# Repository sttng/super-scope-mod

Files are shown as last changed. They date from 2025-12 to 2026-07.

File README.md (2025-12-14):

# super-scope-mod
Tracking, BT communication code, and 3D printer files to make SNES Super Scope work on LCD TVs

## Description
This is the companion code for *element14 Presents* episode 469: "Nintendo Super Scope Mod For Modern Televisions".

Nintendo Super Scope Mod For Modern Televisions (https://www.youtube.com/watch?v=_CQ7ApMLAM0)
 
element14 Community page: https://www.element14.com/community/docs/DOC-95663

# Bill of Material

| Product Name | Manufacturer | Quantity |
| --- | --- | --- |
| RPI4-MODBP-2GB - Single Board Computer, Raspberry Pi 4 Model B, BCM2711 SoC, 2GB DDR4 RAM, USB 3.0, PoE Enabled | RASPBERRY-PI | 1 |
| Development Board, Arduino Uno, ATmega328P MCU, 14 3.3V I/O, 6 Analogue Inputs, 6 PWM Outputs | ARDUINO | 1 |
| RPI NOIR CAMERA BOARD - Daughter Board, Raspberry Pi NoIR Camera Board, Version 2, Sony IMX219 8-Megapixel Sensor | RASPBERRY-PI | 1 |
| MP001243 - AXIAL FAN, RASPBERRY PI 4 POWER HAT CASE | MULTICOMP PRO | 1 |
| Infrared Emitter, High Speed, 850 nm, 3 °, T-1 3/4 (5mm), 10 mW/Sr, 10 ns, 10 ns | VISHAY | 4 |
| LM1881N Video Sync Separator chip | TI | 1 |
| MC14021BCP 8Bit Shift Register chip | Motorola | 1 |
| 680k Ohm resistor | | 1 |
| 0.1 µF ceramic capacitors | | 2 |

# Additional Parts

| Product Name |
| ------------ |
| 3 x 3" Infrared (87C) Polyester Filter |
| Moldable glue, black color |
| HC-06 Bluetooth 2.0 Module |
| 30cm Micro HDMI Male to Micro HDMI Female Extension Cable |
| 30cm USB Type C Extension Cable Male to Female |
| 50cm flat ribbon camera cable for Raspberry Pi cameras |

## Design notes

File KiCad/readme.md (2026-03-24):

# Arduino Nano Shield KiCad 9 files

An Arduino Nano shield version of the Super Scope Mod. It is supposed to go below an Arduino Nano. 
The orientation is marked with the USB (top) marker. This is where the Arduino Nanos USB port is supposed to be (on top), with the shield below.

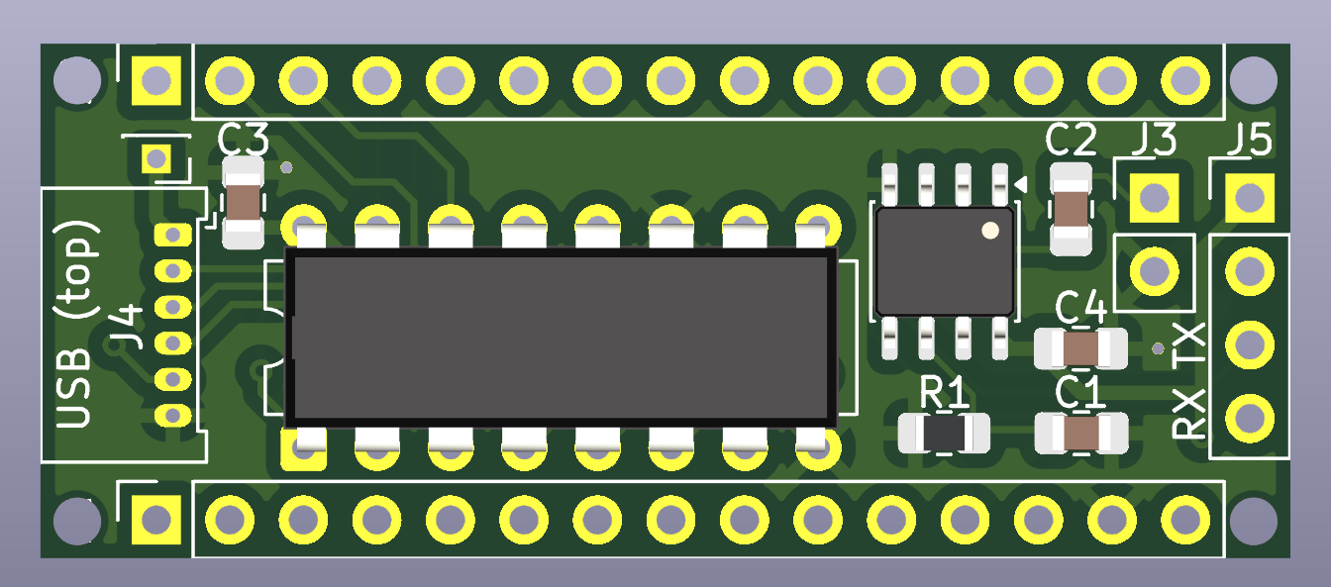
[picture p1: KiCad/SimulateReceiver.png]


## Device

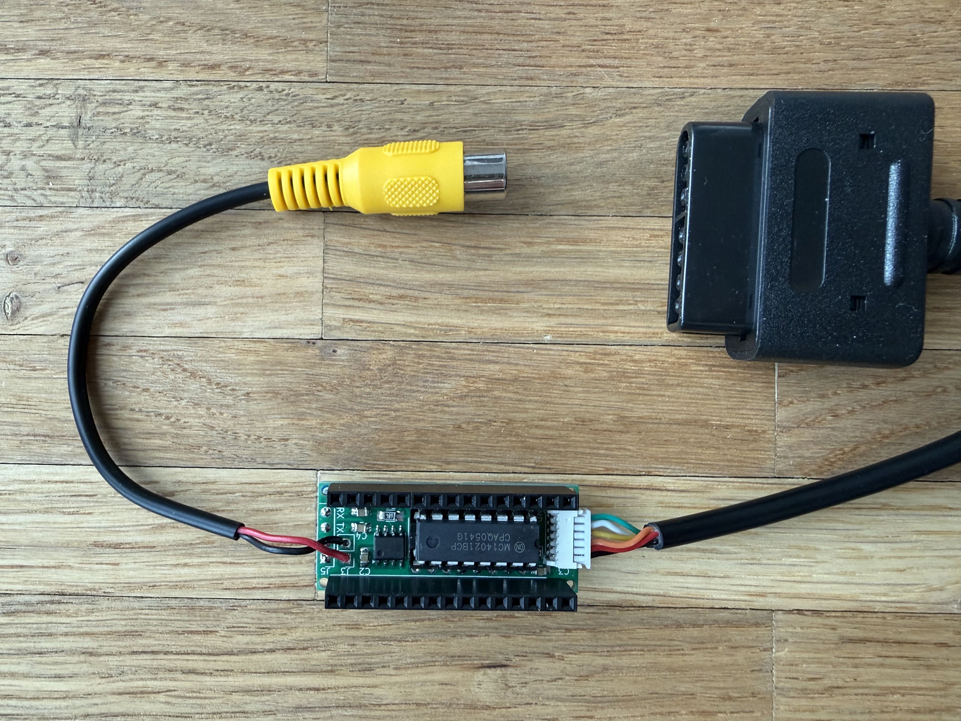
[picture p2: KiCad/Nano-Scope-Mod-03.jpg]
Prototype-1
 

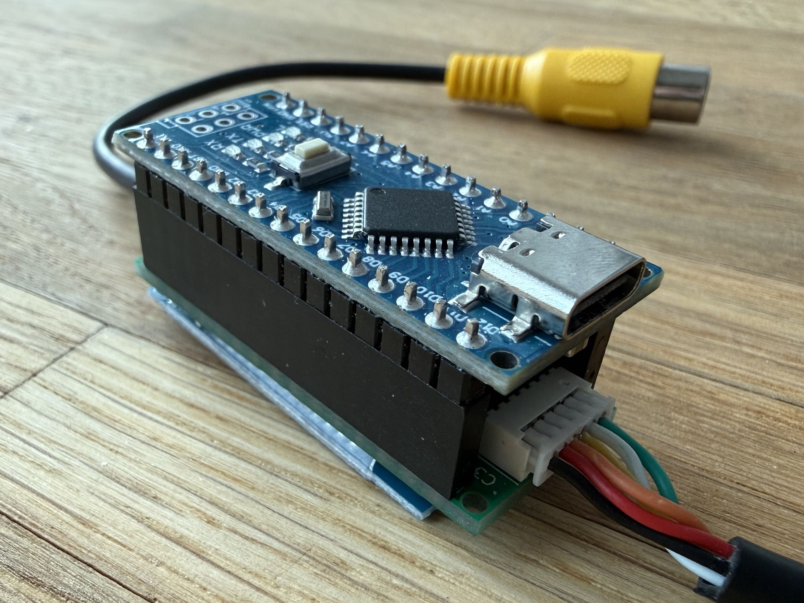
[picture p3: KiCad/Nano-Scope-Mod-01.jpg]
Prototype-3
 

## BoM

| Designator  | Footprint | Quantity | Description |
|---|---|---|---|
| J1, J2 | PinSocket_1x15_P2.54mm_Vertical | 2 | |
| J4 | Molex_PicoBlade_53048-0610_1x06_P1.25mm_Horizontal | 1 | |
| C1,C2,C3,C3 | C_0805_2012Metric_Pad1.18x1.45mm_HandSolder | 4 | 0.1µF |
| R1 | R_0805_2012Metric_Pad1.20x1.40mm_HandSolder | 1 | 680k |
| IC1 | DIP-16_W7.62mm | 1 | MC14021BCP |
| U1 | JEITA_SOIC-8_3.9x4.9mm_P1.27mm | 1 | LM1881M |

# ESP32-S3 Super Mini Shield KiCad 9 files

An ESP32-S3 Super Mini shield version of the Super Scope Mod. It is supposed to go below an ESP32-S3 Super Mini board. 
The orientation is marked with the USB (top) marker. This is where the ESP32-S3 Super Mini USB port is supposed to be (on top), with the shield below.

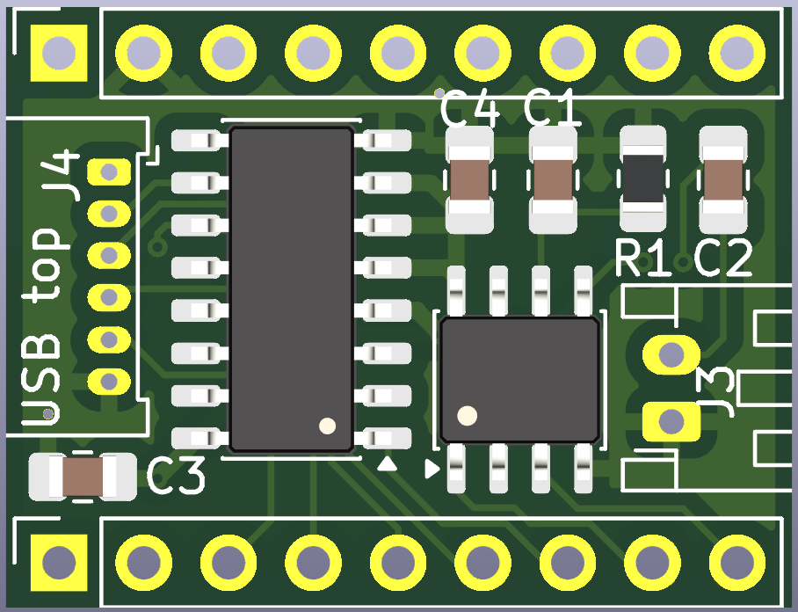
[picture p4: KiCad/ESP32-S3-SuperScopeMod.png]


## Device

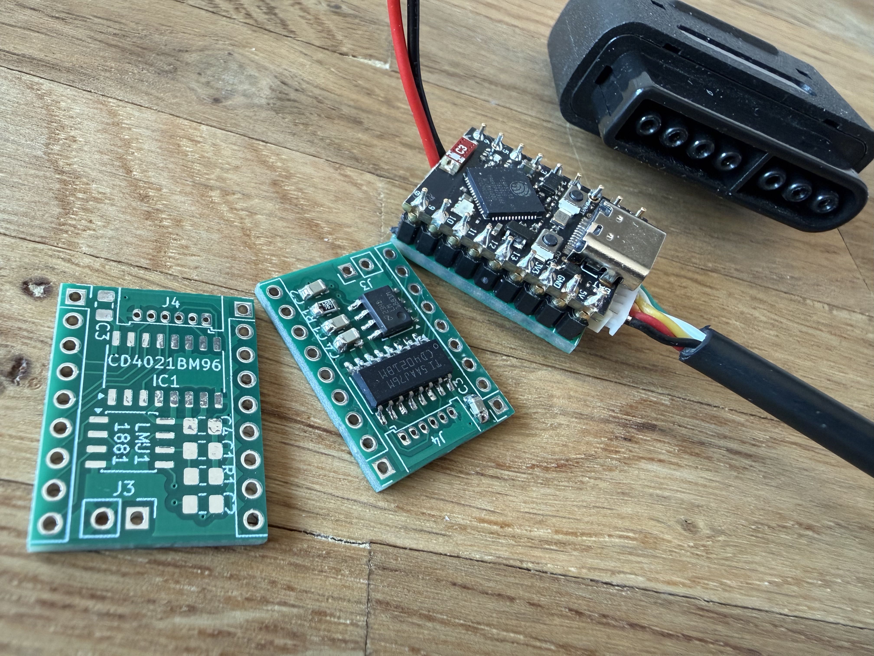
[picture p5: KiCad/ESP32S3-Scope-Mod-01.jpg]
Prototype-ESP32-1
 

## BoM

| Designator  | Footprint | Quantity | Description |
|---|---|---|---|
| J1, J2 | PinSocket_1x09_P2.54mm_Vertical | 2 | |
| J3 | JST PH 1x02 P2.00mm Horizontal | 1 | to Connect to Coax |
| J4 | Molex_PicoBlade_53048-0610_1x06_P1.25mm_Horizontal | 1 | |
| C1,C2,C3,C3 | C_0805_2012Metric_Pad1.18x1.45mm_HandSolder | 4 | 0.1µF |
| R1 | R_0805_2012Metric_Pad1.20x1.40mm_HandSolder | 1 | 680k |
| IC1 | JEITA_SOIC-16_3.9x9.9mm_P1.27mm | 1 | CD4021BM96 |
| U1 | JEITA_SOIC-8_3.9x4.9mm_P1.27mm | 1 | LM1881M |

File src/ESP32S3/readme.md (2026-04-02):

 For ESP32-S3 & ESP32-H2 Super Mini Dev Module

For serial output to work:
  Select Tools > USB CDC On Boot > Enabled from the Arduino IDE menus.

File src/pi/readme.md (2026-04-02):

1) Install OS and updates.
```
sudo apt update
sudo apt upgrade -y
```

2. Installing the LGPIO Library on the Raspberry Pi
https://pimylifeup.com/raspberry-pi-install-lgpio/

We must ensure that we have all the tools needed to compile the library.
```
sudo apt install unzip wget swig build-essential python3-dev python3-setuptools
```

Go to home dir

```
cd ~
```

Download the latest version of the LGPIO library code directly from GitHub

```
wget https://github.com/joan2937/lg/archive/master.zip
```

```
unzip master.zip
cd lg-master
```

```
make
```

```
sudo make install
```

Cleanup

```
cd
rm master.zip
rm -r -f ./lg-master
```

3 .Setup Python Env

```
sudo apt-get install python3-pip
```

```
python3 -m venv venv
source venv/bin/activate
```

```
pip3 install simplepyble
```

```
//pip3 install bleak
//pip3 install RPi.GPIO
pip3 install rpi-lgpio
pip3 install --upgrade imutils
pip3 install scipy
```

#Start Bluetooth Service:
```
sudo systemctl start bluetooth
```
#Unblock Bluetooth (if necessary):
```
sudo rfkill unblock bluetooth
```

Activate Power within bluetoothctl:
#bluetoothctl
Type power on
Type agent on
Type default-agent
Type exit

/usr/local/bin/bleak-lescan

# only Python
Option 1 - Main modules package: pip install opencv-python 

Option 2 - Full package (contains both main modules and contrib/extra modules): pip install opencv-contrib-python (check contrib/extra modules listing from OpenCV documentation)

Packages for server (headless) environments:

Option 3 - Headless main modules package: pip install opencv-python-headless

Option 4 - Headless full package (contains both main modules and contrib/extra modules): pip install opencv-contrib-python-headless

```
pip3 install opencv-contrib-python
```

# If building yourself

You need at least 2GB ZRAM. 

# Install zram tools

```
sudo apt install zram-tools
```

# Disable the current swap

```
sudo swapoff /dev/zram0
```

# Reset the device

```
sudo zramctl --reset /dev/zram0
```

# Set the new size and re-initialize as swap

```
sudo zramctl --find --size 2G --algorithm zstd
sudo mkswap /dev/zram0
sudo swapon /dev/zram0
```

https://qengineering.eu/install-opencv-lite-on-raspberry-pi.html

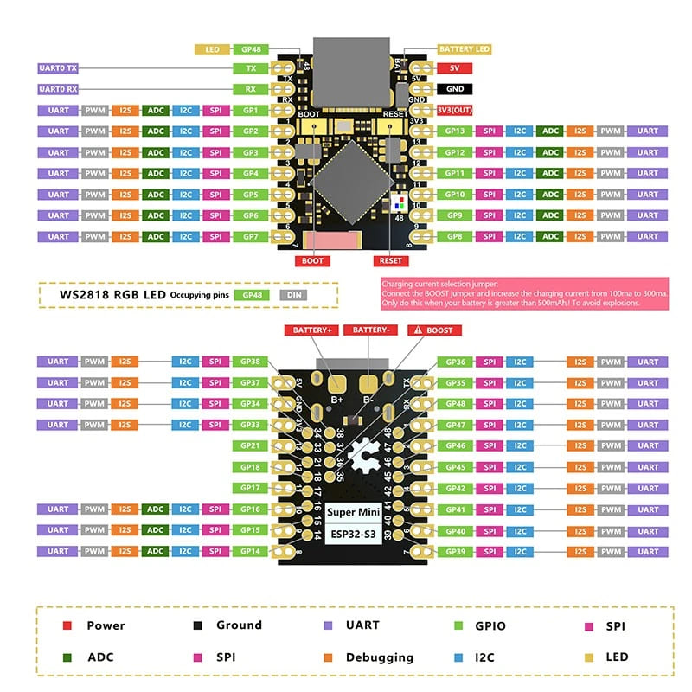
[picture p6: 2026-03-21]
KiCad/SimulateReceiver ESP32-S3-SuperMini/ESP32-S3-SuperMini-Pinout.jpg

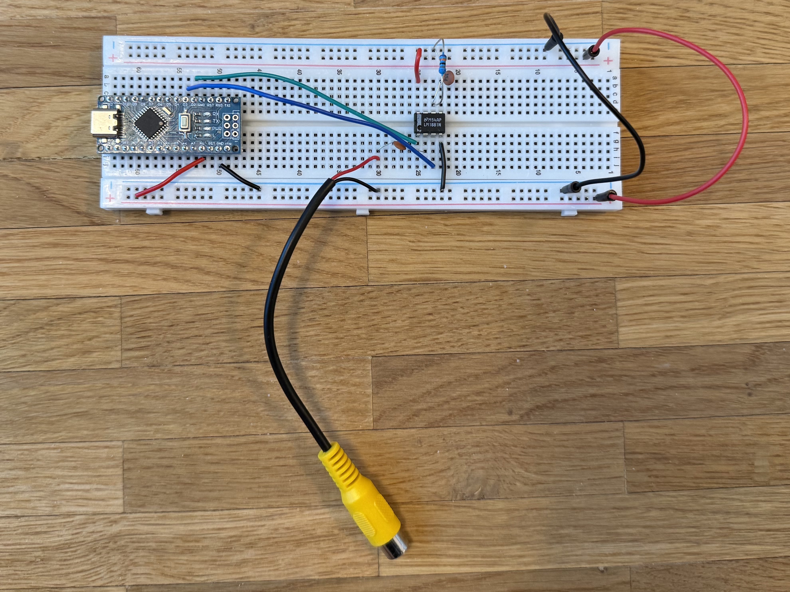
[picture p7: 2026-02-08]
src/arduino/count-screen-lines.jpg

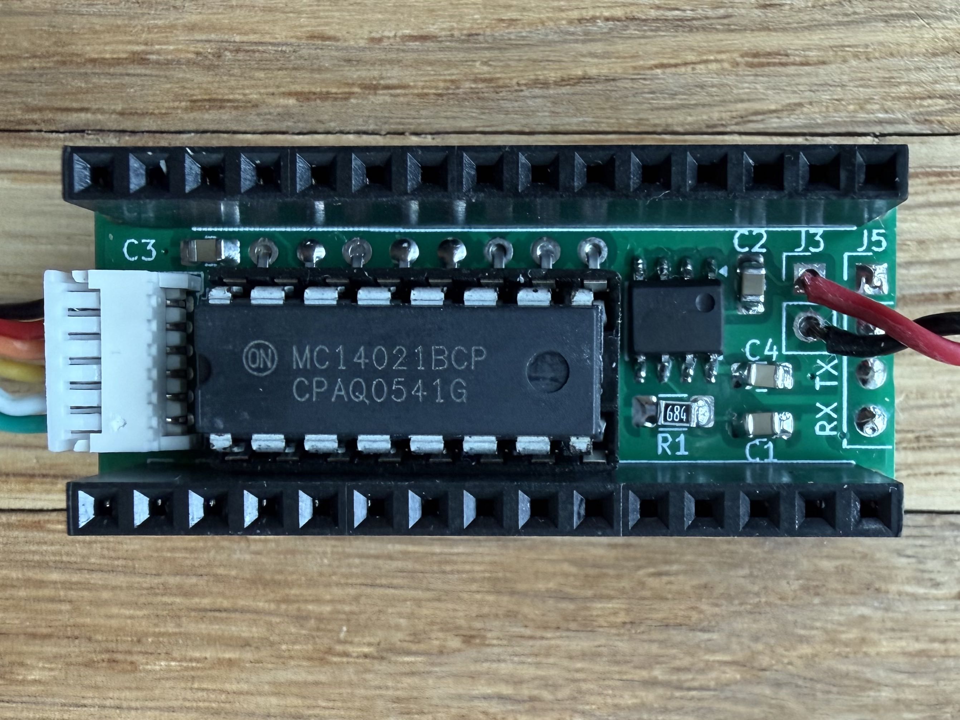
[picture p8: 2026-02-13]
KiCad/Nano-Scope-Mod-02.jpg

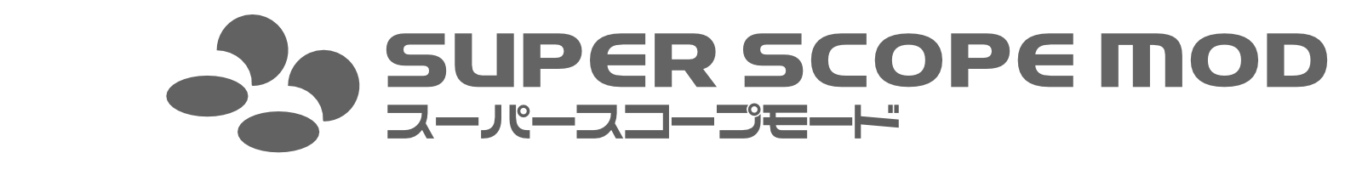
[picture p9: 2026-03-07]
KiCad/Super_Scope_mod.png

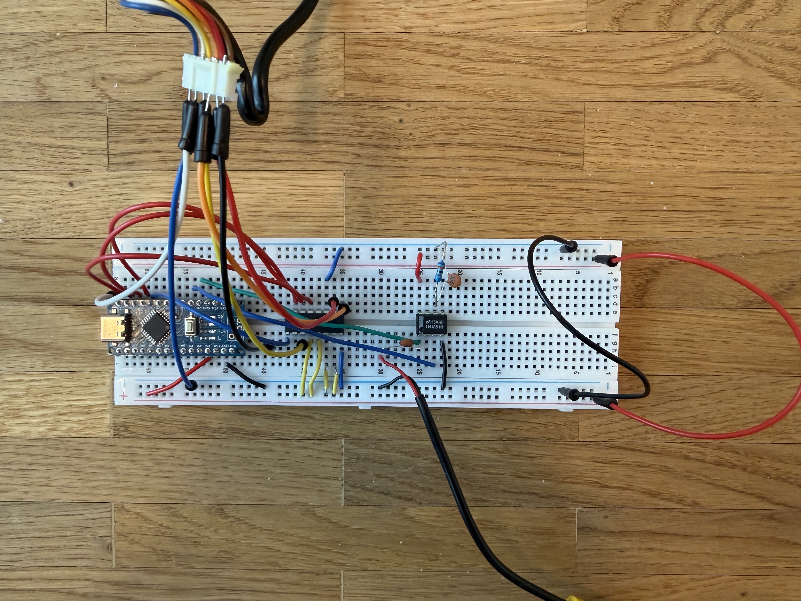
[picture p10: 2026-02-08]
src/arduino/simulate-receiver.jpg

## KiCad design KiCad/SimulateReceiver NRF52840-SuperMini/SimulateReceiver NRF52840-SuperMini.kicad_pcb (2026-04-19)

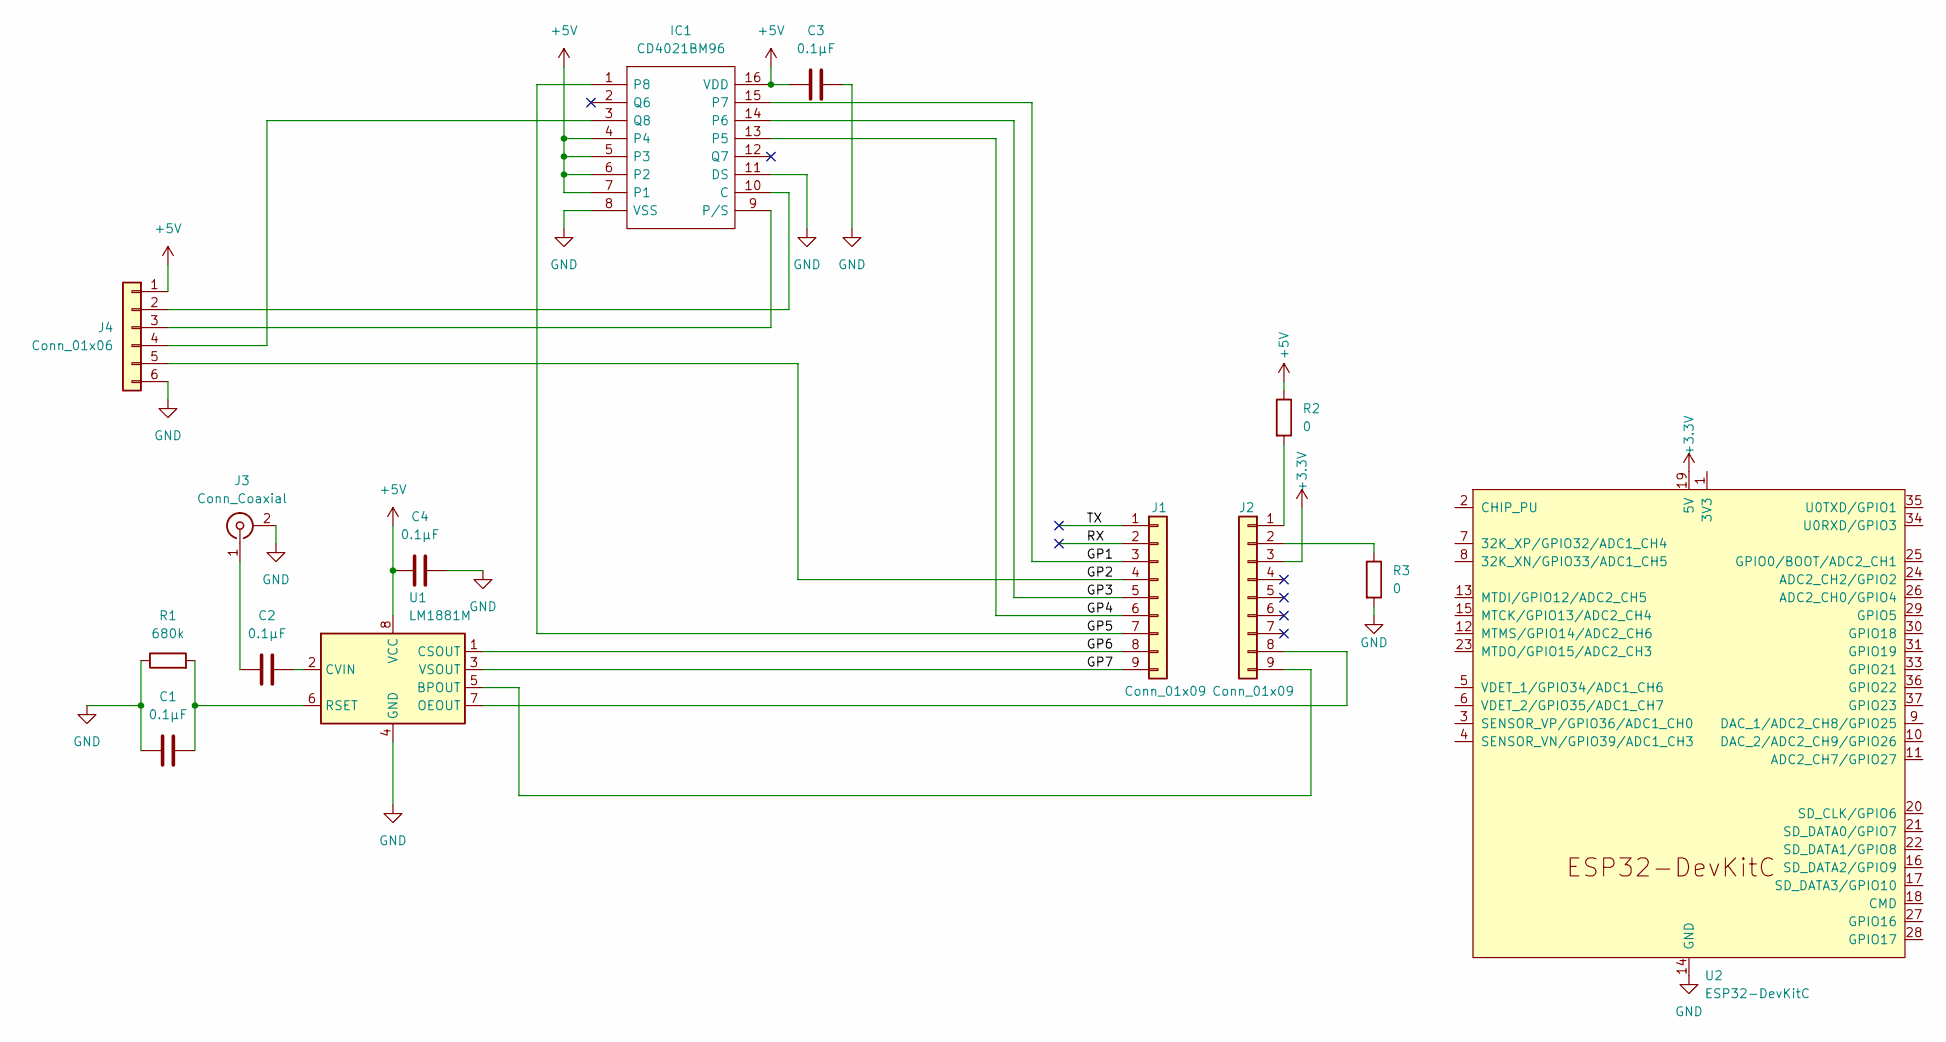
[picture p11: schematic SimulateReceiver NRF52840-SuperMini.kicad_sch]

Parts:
C1, C2, C3, C4: 0.1µF; C_0805_2012Metric_Pad1.18x1.45mm_HandSolder
IC1: CD4021BM96; JEITA_SOIC-16_3.9x9.9mm_P1.27mm; Mouser Part Number 863-MC14021BDG
J1, J2: Conn_01x09; PinSocket_1x09_P2.54mm_Vertical
J3: Conn_Coaxial; JST_PH_S2B-PH-K_1x02_P2.00mm_Horizontal
J4: Conn_01x06; Molex_PicoBlade_53048-0610_1x06_P1.25mm_Horizontal
R1: 680k; R_0805_2012Metric_Pad1.20x1.40mm_HandSolder
R2, R3: 0; R_0603_1608Metric_Pad0.98x0.95mm_HandSolder
U1: LM1881M; JEITA_SOIC-8_3.9x4.9mm_P1.27mm
U2: ESP32-DevKitC; ESP32-S3-SuperMini

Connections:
+3.3V: J2.3, U2.19 (5V)
+5V: C3.1, C4.1, IC1.4, IC1.5 (P3), IC1.6 (P2), IC1.7 (P1), IC1.16 (VDD), J4.1, R2.1, U1.8 (VCC)
/GP1: IC1.15 (P7), J1.3
/GP2: J1.4, J4.5
/GP3: IC1.14 (P6), J1.5
/GP4: IC1.13 (P5), J1.6
/GP5: IC1.1 (P8), J1.7
/GP6: J1.8, U1.1 (CSOUT)
/GP7: J1.9, U1.3 (VSOUT)
/RX: J1.2
/TX: J1.1
GND: C1.1, C3.2, C4.2, IC1.8 (VSS), IC1.11 (DS), J3.2 (Ext), J4.6, R1.1, R3.2, U1.4 (GND), U2.14 (GND), U2.32 (GND), U2.38 (GND)
unnamed: IC1.10 (C), J4.2
unnamed: IC1.9 (P/S), J4.3
unnamed: IC1.3 (Q8), J4.4
unnamed: J2.1, R2.2
unnamed: J2.2, R3.1
unnamed: J2.8, U1.7 (OEOUT)
unnamed: J2.9, U1.5 (BPOUT)
unnamed: C2.1, J3.1 (In)
unnamed: C2.2, U1.2 (CVIN)
unnamed: C1.2, R1.2, U1.6 (RSET)

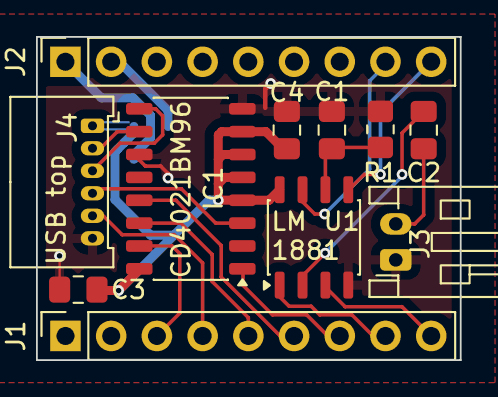
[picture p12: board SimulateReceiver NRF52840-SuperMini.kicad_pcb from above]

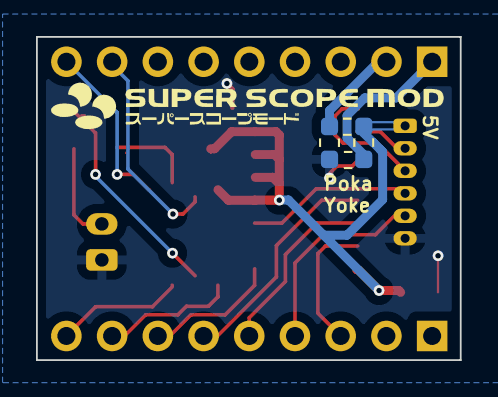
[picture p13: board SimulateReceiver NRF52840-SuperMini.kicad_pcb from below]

Board: 4 copper layers, 23.5 x 18.0 mm, 13 parts (2 on the bottom side), 19 nets.

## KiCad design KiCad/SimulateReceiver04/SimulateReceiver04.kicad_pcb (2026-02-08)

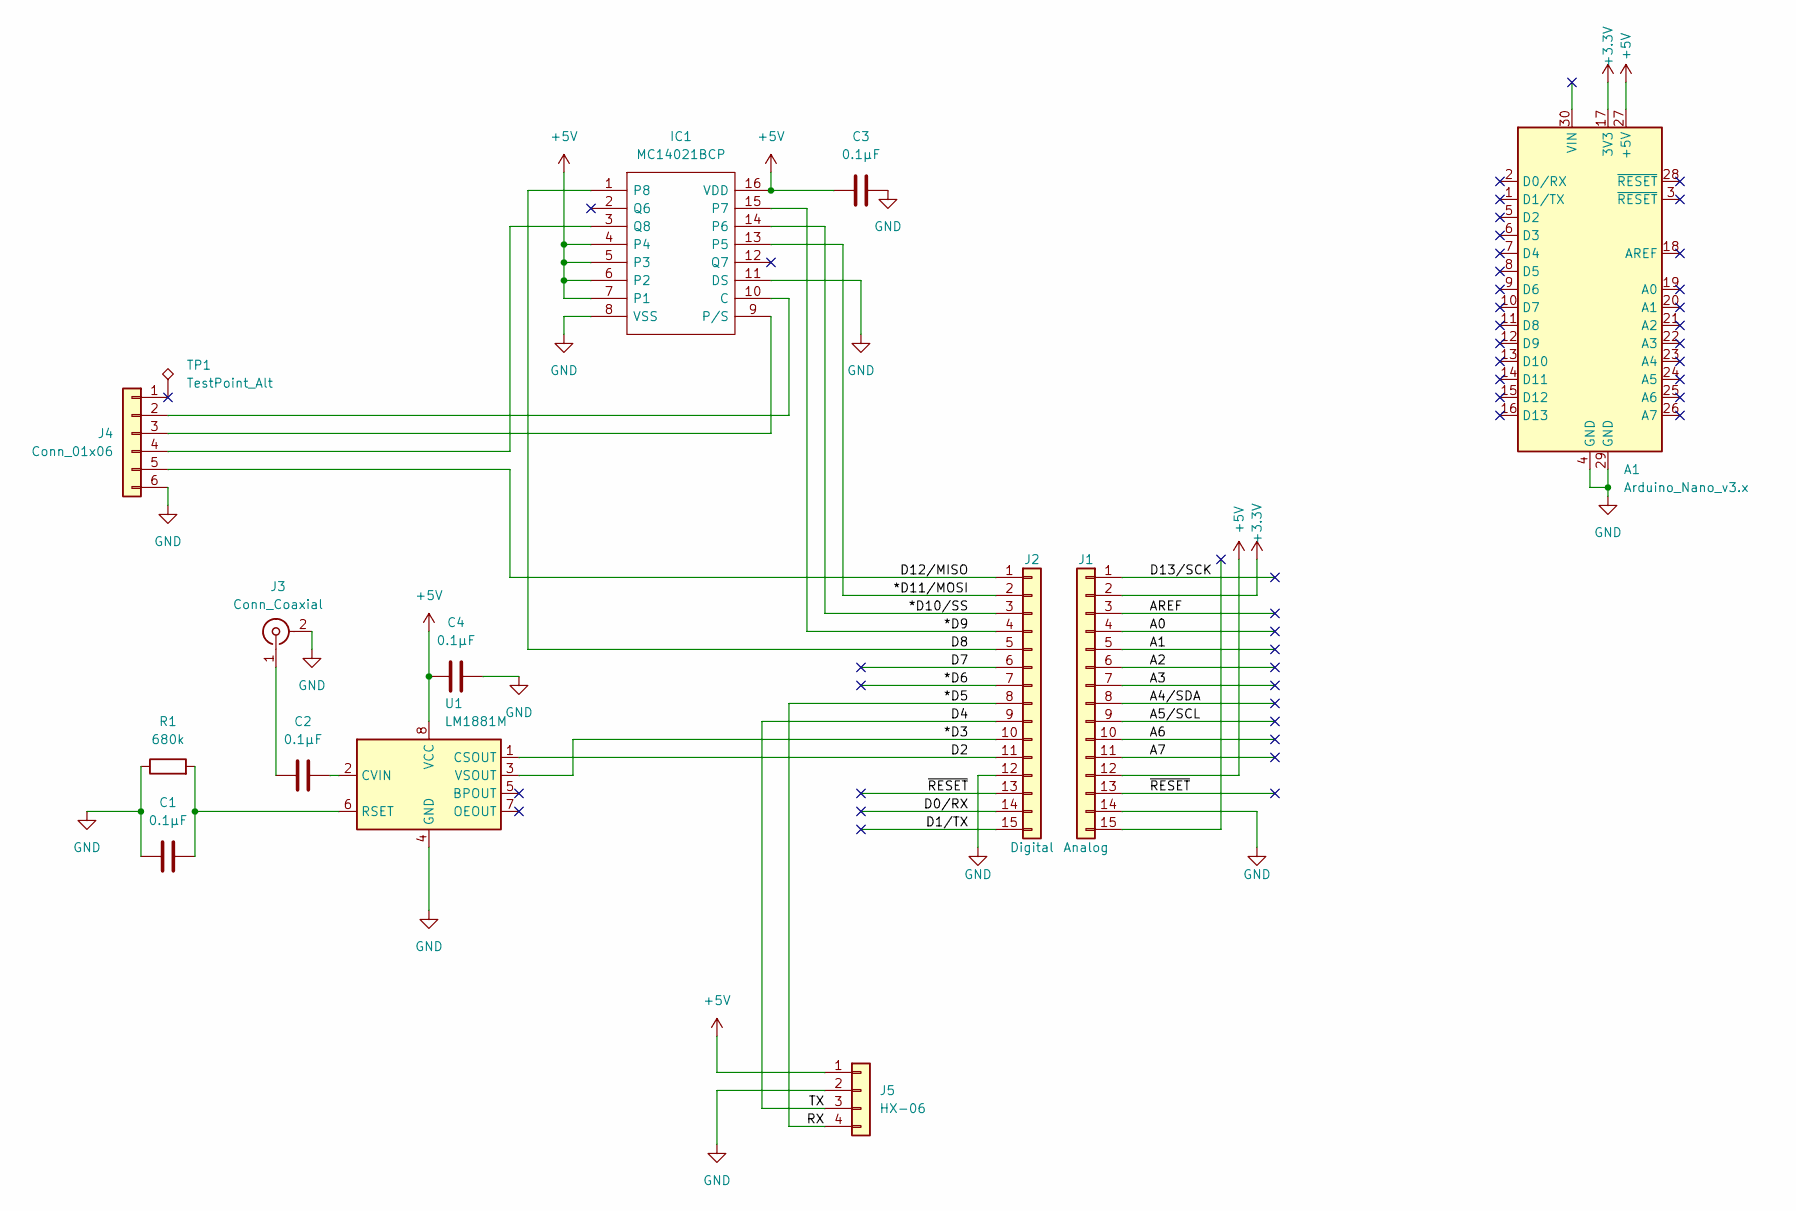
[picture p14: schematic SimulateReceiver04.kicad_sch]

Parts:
A1: Arduino_Nano_v3.x; Arduino_Nano
C1, C2, C3, C4: 0.1µF; C_0805_2012Metric_Pad1.18x1.45mm_HandSolder
IC1: MC14021BCP; DIP-16_W7.62mm; Mouser Part Number 863-MC14021BDG
J1: Analog; PinSocket_1x15_P2.54mm_Vertical
J2: Digital; PinSocket_1x15_P2.54mm_Vertical
J3: Conn_Coaxial; PinHeader_1x02_P2.54mm_Vertical
J4: Conn_01x06; Molex_PicoBlade_53048-0610_1x06_P1.25mm_Horizontal
J5: HX-06; PinHeader_1x04_P2.54mm_Vertical
R1: 680k; R_0805_2012Metric_Pad1.20x1.40mm_HandSolder
TP1: TestPoint_Alt; PinHeader_1x01_P1.27mm_Vertical
U1: LM1881M; JEITA_SOIC-8_3.9x4.9mm_P1.27mm

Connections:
+3.3V: A1.17 (3V3), J1.2
+5V: A1.27 (+5V), C3.1, C4.1, IC1.4, IC1.5 (P3), IC1.6 (P2), IC1.7 (P1), IC1.16 (VDD), J1.12, J5.1, U1.8 (VCC)
/*D3: J2.10, U1.3 (VSOUT)
/*D5: J2.8, J5.4
/*D6: J2.7
/*D9: IC1.15 (P7), J2.4
/*D10/SS: IC1.14 (P6), J2.3
/*D11/MOSI: IC1.13 (P5), J2.2
/A0: J1.4
/A1: J1.5
/A2: J1.6
/A3: J1.7
/A4/SDA: J1.8
/A5/SCL: J1.9
/A6: J1.10
/A7: J1.11
/AREF: J1.3
/D0/RX: J2.14
/D1/TX: J2.15
/D2: J2.11, U1.1 (CSOUT)
/D4: J2.9, J5.3
/D7: J2.6
/D8: IC1.1 (P8), J2.5
/D12/MISO: J2.1, J4.5
/D13/SCK: J1.1
/~RESET: J1.13, J2.13
GND: A1.4 (GND), A1.29 (GND), C1.1, C3.2, C4.2, IC1.8 (VSS), IC1.11 (DS), J1.14, J2.12, J3.2 (Ext), J4.6, J5.2, R1.1, U1.4 (GND)
unnamed: IC1.10 (C), J4.2
unnamed: IC1.9 (P/S), J4.3
unnamed: IC1.3 (Q8), J4.4
unnamed: C2.1, J3.1 (In)
unnamed: C2.2, U1.2 (CVIN)
unnamed: C1.2, R1.2, U1.6 (RSET)

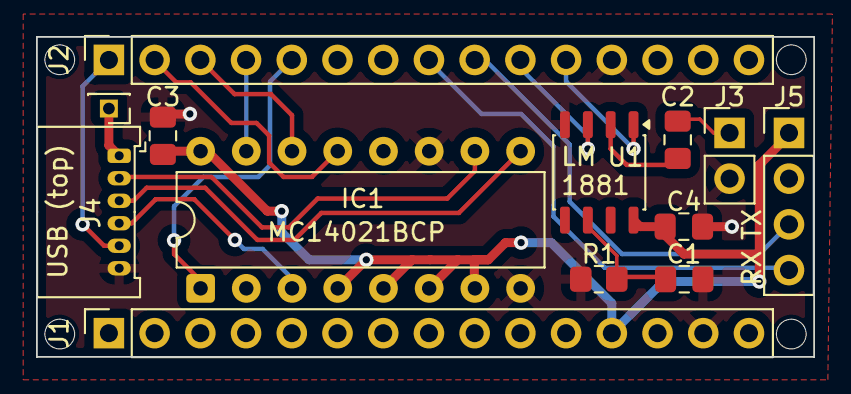
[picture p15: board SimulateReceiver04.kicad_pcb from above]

Board: 4 copper layers, 43.2 x 17.8 mm, 17 parts (0 on the bottom side), 18 nets.

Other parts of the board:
MH1, MH2, MH3, MH4: MountingHole_65mil

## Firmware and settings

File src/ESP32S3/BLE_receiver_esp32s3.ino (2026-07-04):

#include <BLEDevice.h>
#include <BLEServer.h>
#include <BLEUtils.h>
#include <BLE2901.h>

#include <WiFi.h>               // This is the most basic WiFi implimentation
#include "driver/adc.h"         // Allows direct control of ADC for powersaving, can't be <adc.h> for some reason
#include <esp_bt.h>             // Allows direct API control of BT for powersaving
#include <esp_wifi.h>           // Provides direct API control of WiFi radio for powersaving

// See the following for generating UUIDs:
// https://www.uuidgenerator.net/
#define DEVICE_NAME         "SuperScopeMod_ESP32S3"  
#define SERVICE_UUID        "4fafc201-1fb5-459e-8fcc-c5c9c331914b"
#define CHARACTERISTIC_UUID "beb5483e-36e1-4688-b7f5-ea07361b26a8"

BLEServer *pServer = nullptr;
BLECharacteristic *pCharacteristic = nullptr;
bool deviceConnected = false;

const int COMPOSITE_SYNC_PIN = 6;
const int VERTICAL_SYNC_PIN = 7;

const int TRIGGER_PIN = 5;
const int CURSOR_PIN = 1;
const int TURBO_PIN = 3;
const int PAUSE_PIN = 4;
const int EXTERNAL_LATCH_PIN = 2; // Raster gate

const byte BT_MESSAGE_TRIGGER_PRESSED = 231;
const byte BT_MESSAGE_TRIGGER_RELEASED = 232;
const byte BT_MESSAGE_CURSOR_PRESSED = 233;
const byte BT_MESSAGE_CURSOR_RELEASED = 234;
const byte BT_MESSAGE_TURBO_ENABLED = 235;
const byte BT_MESSAGE_TURBO_DISABLED = 236;
const byte BT_MESSAGE_PAUSE_PRESSED = 237;
const byte BT_MESSAGE_PAUSE_RELEASED = 238;
const byte BT_MESSAGE_TV_NOT_VISIBLE = 239;
const byte BT_MESSAGE_AIM_X = 240;
const byte BT_MESSAGE_AIM_Y = 241;

const byte BT_MESSAGE_NONE = 0;
byte lastBluetoothMessage = BT_MESSAGE_NONE;

bool isTriggerPressed = false;
bool isCursorPressed = false;
bool isTurboEnabled = false;
bool isPausePressed = false;
volatile bool isTvVisible = false;

const int minAimLine = 10;
const int maxAimLine = 240;
const int minAimMicroseconds = 5;
const int maxAimMicroseconds = 55;

volatile int aimLine = 120; //(maxAimLine - minAimLine + 1) / 2 + minAimLine;
volatile int aimMicroseconds = 27; //(maxAimMicroseconds - minAimMicroseconds + 1) / 2 + minAimMicroseconds;

volatile int currentLine = 0;



class MyServerCallbacks: public BLEServerCallbacks {
    void onConnect(BLEServer *pServer) {
      //digitalWrite(48, HIGH);
      Serial.println("Client Connected");
      deviceConnected = true;
    };

    void onDisconnect(BLEServer *pServer) {
      //digitalWrite(48, LOW);
      Serial.println("Client Disconnected");
      deviceConnected = false;
      BLEDevice::startAdvertising();
    }
};

class MyCharacteristicCallbacks : public BLECharacteristicCallbacks {
  void onRead(BLECharacteristic *pCharacteristic) {
    uint32_t currentMillis = millis() / 1000;
    pCharacteristic->setValue(0);
  }
};

void setup() {

  esp_wifi_set_mode(WIFI_MODE_NULL);
  WiFi.disconnect(true);  // Disconnect from the network
  WiFi.mode(WIFI_OFF);    // Switch WiFi off
  esp_wifi_stop();
  //adc_power_release(); 


  // Set the CPU frequency to 80 MHz for consumption optimization
  //setCpuFrequencyMhz(80);
  
  Serial.begin(9600);
  pinMode(48, OUTPUT);
  digitalWrite(48, HIGH);
  delay(1000);
  digitalWrite(48, LOW);
  delay(1000);
  
  // Print the XTAL crystal frequency
  //Serial.print("XTAL Crystal Frequency: ");
  //Serial.print(getXtalFrequencyMhz());
  //Serial.println(" MHz");

  // Print the CPU frequency
  Serial.print("CPU Frequency: ");
  Serial.print(getCpuFrequencyMhz());
  Serial.println(" MHz");

  // Print the APB bus frequency
  Serial.print("APB Bus Frequency: ");
  Serial.print(getApbFrequency());
  Serial.println(" Hz");
  //End CPU frequency change
  
 

  // Create the BLE Device
  BLEDevice::init(DEVICE_NAME);

  // Create BLE Server
  pServer = BLEDevice::createServer();
  pServer->setCallbacks(new MyServerCallbacks());

  // Create the BLE Service
  BLEService *pService = pServer->createService(SERVICE_UUID);

  // Create BLE Characteristic
  pCharacteristic = pService->createCharacteristic(
    CHARACTERISTIC_UUID,
    BLECharacteristic::PROPERTY_READ | 
    BLECharacteristic::PROPERTY_WRITE);
  
  pCharacteristic->setCallbacks(new MyCharacteristicCallbacks());

  //pCharacteristic->setValue("Super Scope Chars");

  // Descriptors
  BLE2901 *pDescriptor_2901 = new BLE2901();
  pDescriptor_2901->setDescription("SuperScope Data");
  pCharacteristic->addDescriptor(pDescriptor_2901);

  // Start the Service
  pService->start();

  // Start BLE advertising
  BLEAdvertising *pAdvertising = BLEDevice::getAdvertising();
  pAdvertising->addServiceUUID(pService->getUUID());
  pAdvertising->setScanResponse(true);
  //pAdvertising->setMinPreferred(0x06);
  pAdvertising->setMinPreferred(0x12);
  BLEDevice::startAdvertising();

  //Setup Super Scope Mod Pins, etc
  pinMode(COMPOSITE_SYNC_PIN, INPUT);
  pinMode(VERTICAL_SYNC_PIN, INPUT);

  pinMode(TRIGGER_PIN, OUTPUT);
  pinMode(CURSOR_PIN, OUTPUT);
  pinMode(TURBO_PIN, OUTPUT);
  pinMode(PAUSE_PIN, OUTPUT);
  pinMode(EXTERNAL_LATCH_PIN, OUTPUT);

  digitalWrite(TRIGGER_PIN, HIGH);
  digitalWrite(CURSOR_PIN, HIGH);
  digitalWrite(TURBO_PIN, HIGH);
  digitalWrite(PAUSE_PIN, HIGH);
  digitalWrite(EXTERNAL_LATCH_PIN, HIGH);

  attachInterrupt(digitalPinToInterrupt(COMPOSITE_SYNC_PIN), handleCompositeSync, RISING);
  attachInterrupt(digitalPinToInterrupt(VERTICAL_SYNC_PIN), handleVerticalSync, RISING);
  // Finished Super Scope Mod Setup

  Serial.println("Super Scope Mod-esp32s3 BLE receiver started.");

}

void loop() {

  // Process commands when a device is connected.
  if (deviceConnected && pCharacteristic->getValue().length() > 0) {
    String value = pCharacteristic->getValue().c_str();

    //Serial.println(value.toInt());
    int inputByte = value.toInt();

    switch (inputByte) {
      case BT_MESSAGE_TRIGGER_PRESSED:
        digitalWrite(TRIGGER_PIN, LOW);

        delay(250);
        digitalWrite(TRIGGER_PIN, HIGH);

        Serial.println("Trigger pressed.");
        pCharacteristic->setValue(0); //Set Characterstic back to 0.
        break;
      case BT_MESSAGE_TRIGGER_RELEASED:
        digitalWrite(TRIGGER_PIN, HIGH);
        Serial.println("Trigger released.");
        pCharacteristic->setValue(0); //Set Characterstic back to 0.
        break;
      case BT_MESSAGE_CURSOR_PRESSED:
        digitalWrite(CURSOR_PIN, LOW);
        Serial.println("Cursor pressed.");
        pCharacteristic->setValue(0); //Set Characterstic back to 0.
        break;
      case BT_MESSAGE_CURSOR_RELEASED:
        digitalWrite(CURSOR_PIN, HIGH);
        Serial.println("Cursor released.");
        pCharacteristic->setValue(0); //Set Characterstic back to 0.
        break;
      case BT_MESSAGE_TURBO_ENABLED:
        digitalWrite(TURBO_PIN, LOW);
        Serial.println("Turbo enabled.");
        pCharacteristic->setValue(0); //Set Characterstic back to 0.
        break;
      case BT_MESSAGE_TURBO_DISABLED:
        digitalWrite(TURBO_PIN, HIGH);
        Serial.println("Turbo disabled.");
        pCharacteristic->setValue(0); //Set Characterstic back to 0.
        break;
      case BT_MESSAGE_PAUSE_PRESSED:
        digitalWrite(PAUSE_PIN, LOW);
        Serial.println("Pause pressed.");
        pCharacteristic->setValue(0); //Set Characterstic back to 0.
        break;
      case BT_MESSAGE_PAUSE_RELEASED:
        digitalWrite(PAUSE_PIN, HIGH);
        Serial.println("Pause released.");
        pCharacteristic->setValue(0); //Set Characterstic back to 0.
        break;
      case BT_MESSAGE_TV_NOT_VISIBLE:
        isTvVisible = false;
        pCharacteristic->setValue(0); //Set Characterstic back to 0.
        break;
      case BT_MESSAGE_AIM_X:
        pCharacteristic->setValue(0); //Set Characterstic back to 0.
      case BT_MESSAGE_AIM_Y:
        isTvVisible = true;
        pCharacteristic->setValue(0); //Set Characterstic back to 0.
        break;
    }

    /*if (inputByte > 230) {
      lastBluetoothMessage = inputByte;
      pCharacteristic->setValue(0); //Set Characterstic back to 0.
    }
    else {
      switch (lastBluetoothMessage) {
        case BT_MESSAGE_AIM_X:
          aimMicroseconds = inputByte + minAimMicroseconds;
          pCharacteristic->setValue(0); //Set Characterstic back to 0.
          break;
        case BT_MESSAGE_AIM_Y:
          aimLine = inputByte + minAimLine;
          pCharacteristic->setValue(0); //Set Characterstic back to 0.
          break;
      }
    }*/
  }
}

void ARDUINO_ISR_ATTR handleCompositeSync() {
  currentLine++;
  //if (isTvVisible && currentLine == aimLine) {
  if (currentLine == aimLine) {
    delayMicroseconds(aimMicroseconds);
    digitalWrite(EXTERNAL_LATCH_PIN, LOW);
    digitalWrite(EXTERNAL_LATCH_PIN, HIGH);
  }
}

void ARDUINO_ISR_ATTR handleVerticalSync() {
  currentLine = 0;
}

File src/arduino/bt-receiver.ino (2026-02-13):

//#include <SoftwareSerial.h>
#include <PostNeoSWSerial.h>

const int COMPOSITE_SYNC_PIN = 2;
const int VERTICAL_SYNC_PIN = 3;

const int BLUETOOTH_RX_PIN = 4;
const int BLUETOOTH_TX_PIN = 5;

const int TRIGGER_PIN = 8;
const int CURSOR_PIN = 9;
const int TURBO_PIN = 10;
const int PAUSE_PIN = 11;
const int EXTERNAL_LATCH_PIN = 12;  // Raster gate

const byte BT_MESSAGE_TRIGGER_PRESSED = 231;
const byte BT_MESSAGE_TRIGGER_RELEASED = 232;
const byte BT_MESSAGE_CURSOR_PRESSED = 233;
const byte BT_MESSAGE_CURSOR_RELEASED = 234;
const byte BT_MESSAGE_TURBO_ENABLED = 235;
const byte BT_MESSAGE_TURBO_DISABLED = 236;
const byte BT_MESSAGE_PAUSE_PRESSED = 237;
const byte BT_MESSAGE_PAUSE_RELEASED = 238;
const byte BT_MESSAGE_TV_NOT_VISIBLE = 239;
const byte BT_MESSAGE_AIM_X = 240;
const byte BT_MESSAGE_AIM_Y = 241;

const byte BT_MESSAGE_NONE = 0;
byte lastBluetoothMessage = BT_MESSAGE_NONE;

bool isTriggerPressed = false;
bool isCursorPressed = false;
bool isTurboEnabled = false;
bool isPausePressed = false;
bool isTvVisible = false;

const int minAimLine = 10;
const int maxAimLine = 240;
const int minAimMicroseconds = 5;
const int maxAimMicroseconds = 55;

int aimLine = (maxAimLine - minAimLine + 1) / 2 + minAimLine;
int aimMicroseconds = (maxAimMicroseconds - minAimMicroseconds + 1) / 2 + minAimMicroseconds;

volatile int currentLine = 0;

//SoftwareSerial bluetoothSerial(BLUETOOTH_RX_PIN, BLUETOOTH_TX_PIN);
PostNeoSWSerial bluetoothSerial(BLUETOOTH_RX_PIN, BLUETOOTH_TX_PIN);

void setup() {
  bluetoothSerial.begin(9600);
  Serial.begin(9600);

  pinMode(COMPOSITE_SYNC_PIN, INPUT);
  pinMode(VERTICAL_SYNC_PIN, INPUT);

  pinMode(TRIGGER_PIN, OUTPUT);
  pinMode(CURSOR_PIN, OUTPUT);
  pinMode(TURBO_PIN, OUTPUT);
  pinMode(PAUSE_PIN, OUTPUT);
  pinMode(EXTERNAL_LATCH_PIN, OUTPUT);

  digitalWrite(TRIGGER_PIN, HIGH);
  digitalWrite(CURSOR_PIN, HIGH);
  digitalWrite(TURBO_PIN, HIGH);
  digitalWrite(PAUSE_PIN, HIGH);
  digitalWrite(EXTERNAL_LATCH_PIN, HIGH);

  attachInterrupt(digitalPinToInterrupt(COMPOSITE_SYNC_PIN), handleCompositeSync, RISING);
  attachInterrupt(digitalPinToInterrupt(VERTICAL_SYNC_PIN), handleVerticalSync, RISING);

  Serial.println("Super Scope BT receiver started.");
}

void loop() {
  if (bluetoothSerial.available() > 0) {
    int inputByte = bluetoothSerial.read();

    switch (inputByte) {
      case BT_MESSAGE_TRIGGER_PRESSED:
        digitalWrite(TRIGGER_PIN, LOW);
        Serial.println("Trigger pressed.");
        break;
      case BT_MESSAGE_TRIGGER_RELEASED:
        digitalWrite(TRIGGER_PIN, HIGH);
        Serial.println("Trigger released.");
        break;
      case BT_MESSAGE_CURSOR_PRESSED:
        digitalWrite(CURSOR_PIN, LOW);
        Serial.println("Cursor pressed.");
        break;
      case BT_MESSAGE_CURSOR_RELEASED:
        digitalWrite(CURSOR_PIN, HIGH);
        Serial.println("Cursor released.");
        break;
      case BT_MESSAGE_TURBO_ENABLED:
        digitalWrite(TURBO_PIN, LOW);
        Serial.println("Turbo enabled.");
        break;
      case BT_MESSAGE_TURBO_DISABLED:
        digitalWrite(TURBO_PIN, HIGH);
        Serial.println("Turbo disabled.");
        break;
      case BT_MESSAGE_PAUSE_PRESSED:
        digitalWrite(PAUSE_PIN, LOW);
        Serial.println("Pause pressed.");
        break;
      case BT_MESSAGE_PAUSE_RELEASED:
        digitalWrite(PAUSE_PIN, HIGH);
        Serial.println("Pause pressed.");
        break;
      case BT_MESSAGE_TV_NOT_VISIBLE:
        isTvVisible = false;
        break;
      case BT_MESSAGE_AIM_X:
      case BT_MESSAGE_AIM_Y:
        isTvVisible = true;
        break;
    }

    if (inputByte > 230) {
      lastBluetoothMessage = inputByte;
    }
    else {
      switch (lastBluetoothMessage) {
        case BT_MESSAGE_AIM_X:
          aimMicroseconds = inputByte + minAimMicroseconds;
          break;
        case BT_MESSAGE_AIM_Y:
          aimLine = inputByte + minAimLine;
          break;
      }
    }
  }
}

void handleCompositeSync() {
  currentLine++;
  
  if (isTvVisible && currentLine == aimLine) {
    delayMicroseconds(aimMicroseconds);
    digitalWrite(EXTERNAL_LATCH_PIN, LOW);
    delayMicroseconds(5);
    digitalWrite(EXTERNAL_LATCH_PIN, HIGH);
  }
}

void handleVerticalSync() {
  currentLine = 0;
}
